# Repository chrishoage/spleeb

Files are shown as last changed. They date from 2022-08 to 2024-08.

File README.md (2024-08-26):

# Spleeb

Another split keyboard... a "Spleeb".

This split keyboard is created using [Ergogen](https://github.com/ergogen/ergogen/) and the routing done manually, copied back into the yaml file. This was inspired a lot by the Ergodash which I used for about a year but wanted something that fit my use and hands a bit better.

## ‼ NOTE ‼

Photos are pictured with heat set inserts in the bottom chassis that **_ARE NOT_** present in the STEP or Fusion 360 files. I was not happy with how the approach I took worked, and didn't want to release something that people may actually use (like the original touchpad bracket which was particularly poorly designed). I didn't want to reprint the bottom just to take some photos. The models in this repo are exactly the same, I just removed the holes for the heat set inserts on the side.

You can read more about the [Spleeb Chassis 1.2 revision in the Pull Request which added it](https://github.com/chrishoage/spleeb/pull/5).

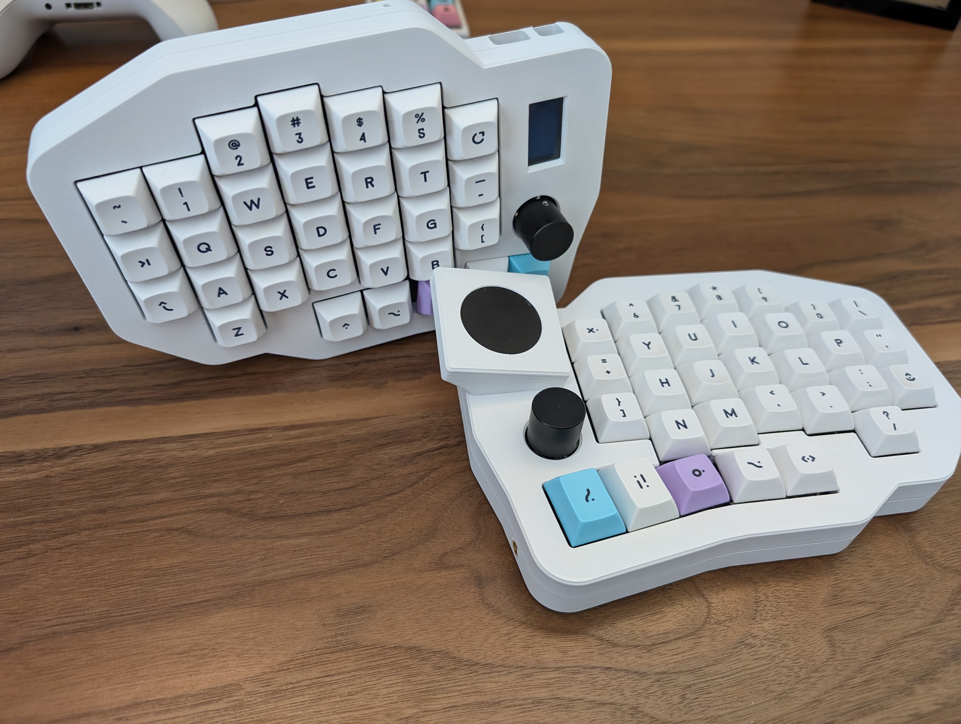
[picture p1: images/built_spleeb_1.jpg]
Spleeb Feature Photo

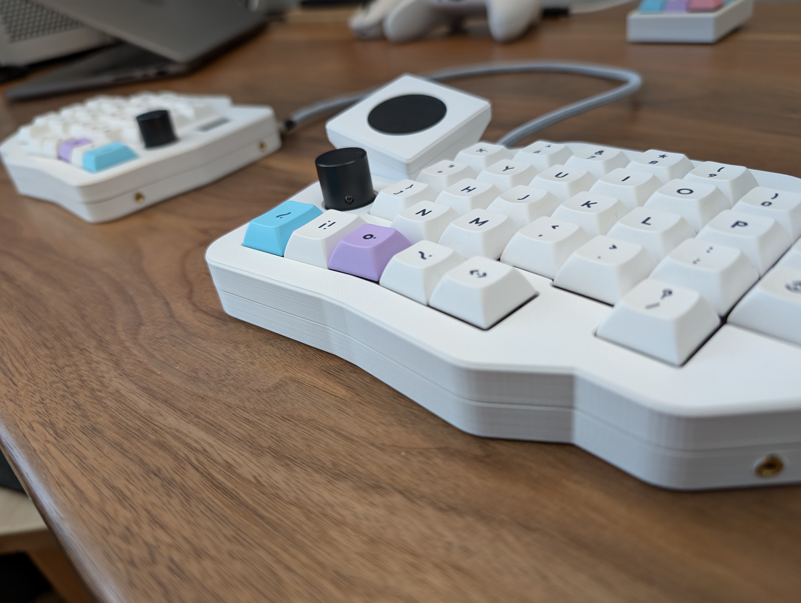
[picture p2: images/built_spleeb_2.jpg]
Spleeb Feature Photo

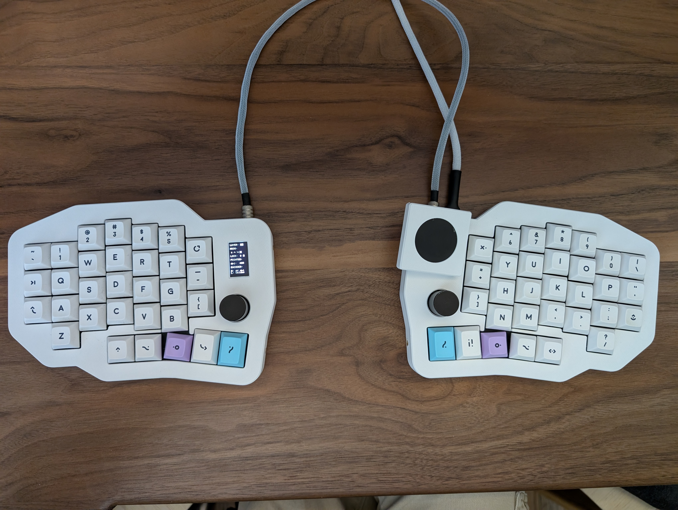
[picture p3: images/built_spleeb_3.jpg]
Spleeb Feature Photo

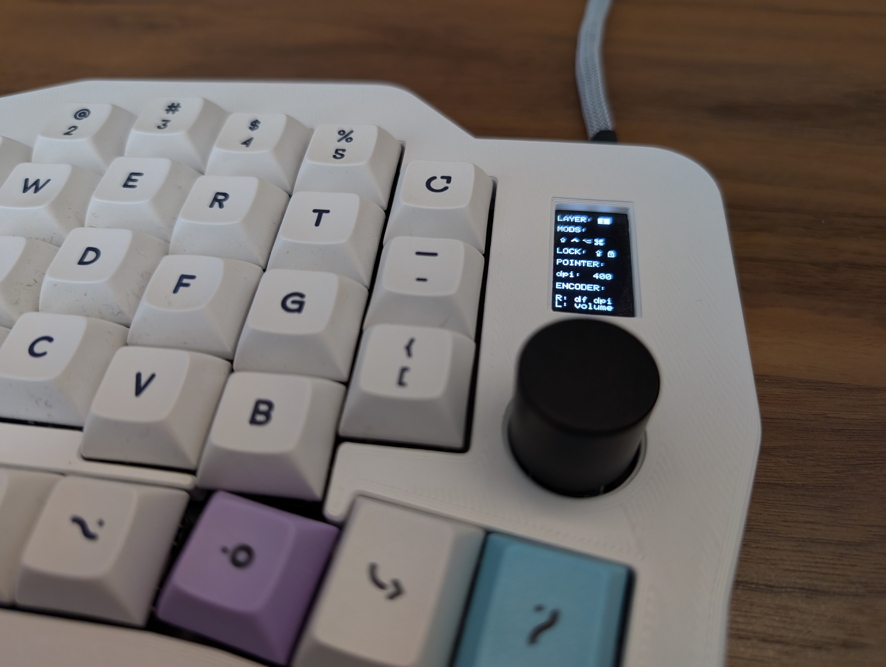
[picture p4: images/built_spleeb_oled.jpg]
Spleeb Feature Photo


### Features

- Reversible PCB
- Optional rotary encoder replacing the bottom left key switch
- OLED screen covering the MCU on the inside of the board
- No acrylic case, only 3D printed case and plate, or cut plate
- No RGB (a joke - I don't use LEDs on keyboards but am open to accepting PRs if someone wants to do the work)

| Left | Right |
| --- | --- |
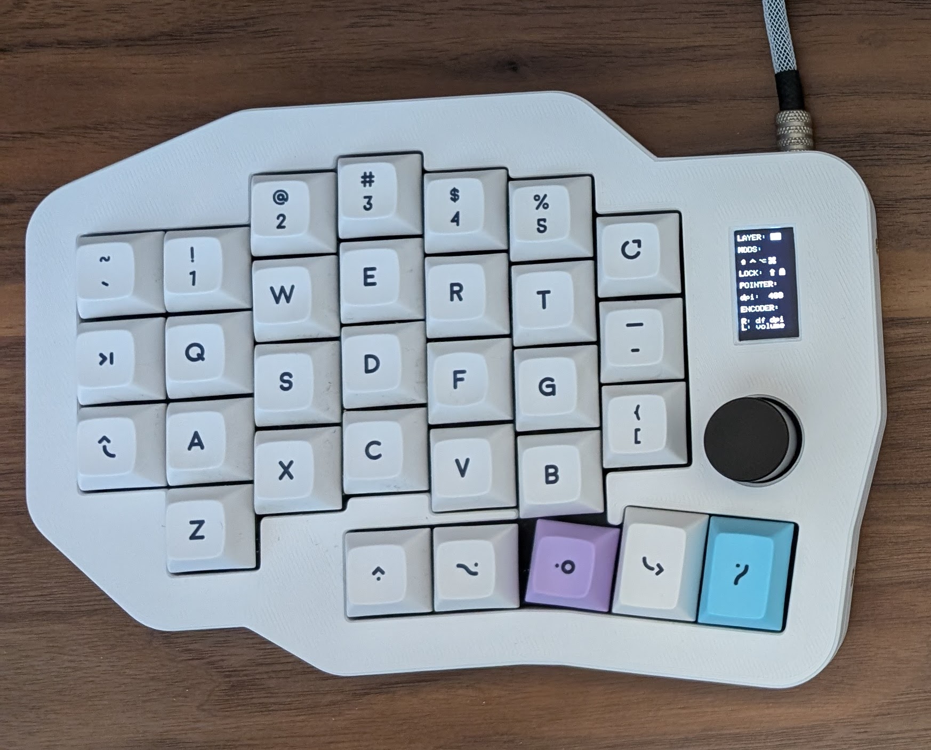
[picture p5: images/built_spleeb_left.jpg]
Left Spleeb
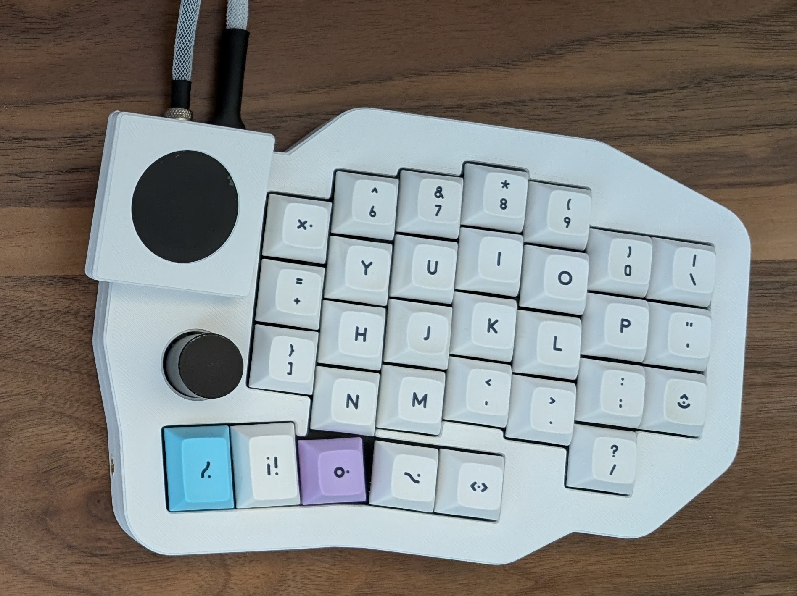
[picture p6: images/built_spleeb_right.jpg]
Right Spleeb
|  |  |
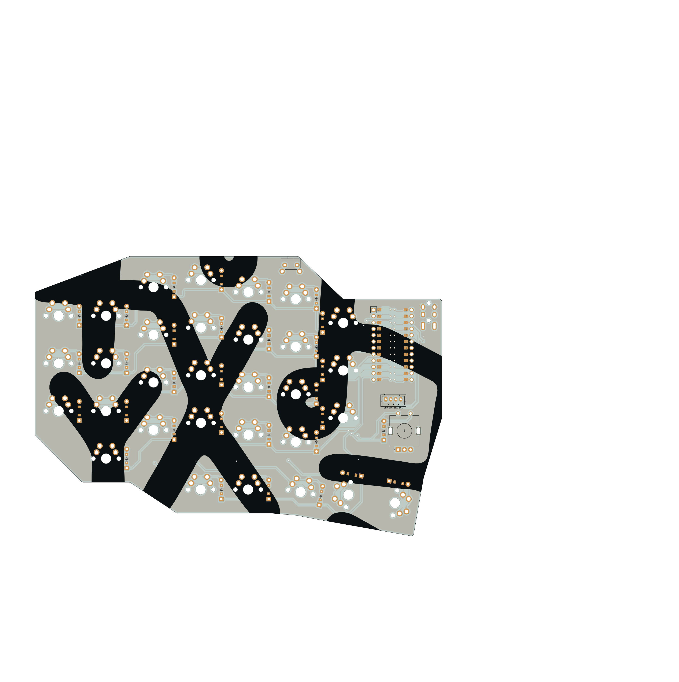
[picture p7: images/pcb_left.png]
Left Spleeb
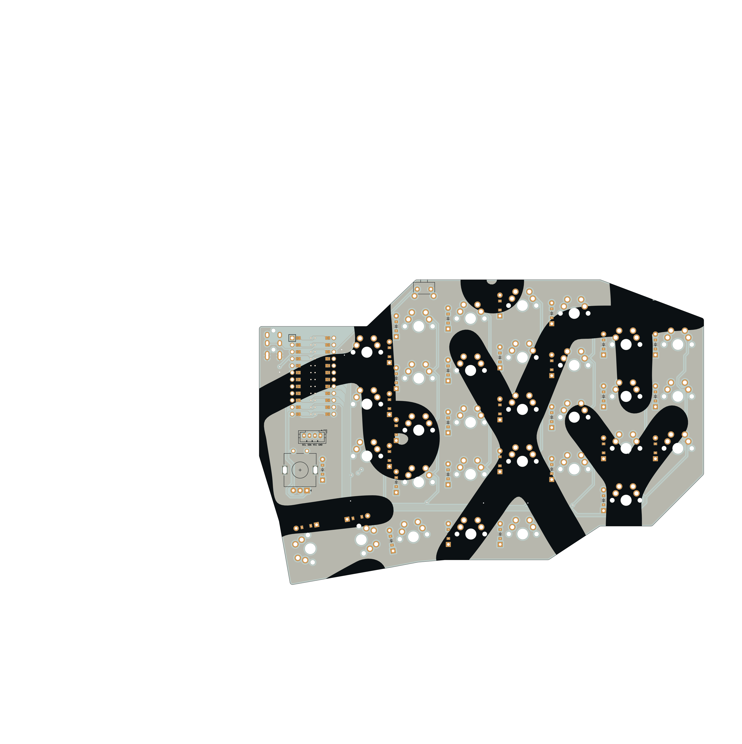
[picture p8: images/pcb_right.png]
Right Spleeb
|  |  |

### Motivation

I'm not a fan of excessive layers, and many of the popular split keyboards are 3x5 and make heavy use of layers. I used the Ergodash for a while but found the placement of the mods to be uncomfortable, and the top row of the thumb cluster to be unused. Seeing some keyboards (like the [bastard keyboards' dilemma](https://bastardkb.com/dilemma/)) which leveraged the Cirque touchpad inspired me to create my own keyboard which allowed for the layout I wanted, along with all the bells and whistles like rotary encoders, oled screen and touchpad. A secondary purpose of this was to learn Fusion 360, KiCad, and a teensy tiny bit of C and electrical engineering.

### BOM

| Item | Quantity | Notes |
| --- | --- | --- |
| Spleeb PCB | 2 | |
| Spleeb Plate | 2 | Intended to be cut from FR4 during PCB fab but this can be 3D printed. Extrude the plate dxf to 1.5mm and it will be 3d printable (fit accuracy depends on your printer) |
| Cirque 35mm Touchpad Flat overlay TM035035 | 1 | i2c only. The SPI version can be modified to use i2c. |
| SSD1306 128x64 OLED | 1 | DIYmall model and footprint used in chassis model. Other brands may have fit issues with out modification of the model. |
| Pro Micro pin MCU | 2 | RP2040 recomended. Boardsource Blok used in build |
| MX switches | 62 | |
| 1u keycaps | 58 | |
| 1.25u keycaps | 4 | |
| EC11 Encoder | 2 | Alps Alpine EC11N1524402 used in build |
| Encoder Kob | 2 | 18mm diameter |
| 1N4148 Through Hole Diodes | 64 | SMD diodes supported on PCB but this has not been tested |
| PJ-320A 3.5 mm jack | 2 | |
| Alps Alpine SKHLLCA010 | 2 | Reset Switch |
| JST PH 2.0 mm 4 pin straight connector | 2 | These are optional. Wires can be soldered directly to the though hole pads on the PCB. The connectors make disassembly easier. |
| Mill-Max 315-93 Low Profile Sockets | 48 | These are optional. However the height of regular headers is slightly higher than these, so may need adjusting to the USB cutout |
| Mill-Max 3320 Socket Pins | 48 | These are optional. These are for the Mill-Max sockets |
| Mill-Max 3305-1 Switch Sockets | 124 | These are optional. These allow switches to be swapped with out resoldering |
| M3 M3x5x4 threaded heat set inserts | 8 | Used to fasten bottom to top of chassis. (Same as the Voron 2.4/Trident BOM) |
| M3 12mm length socket head screws | 8 | Used to fasten bottom to top of chassis. 10mm _should_ work as well. |
| M2 4mm installed length threaded heat set inserts | 10 | Used to fasten plate to top and Cirque bracket to top. Up to 20 may be used depending on how much stiffness in the plate is desired. |
| M2 8mm length ultra low profile screws | 8 | Used to attach plate to top. Minimum 8. Up to 20 may be used depending on how many M2 heat set inserts are installed top top. |
| Silicone O-Rings, 4mm OD 1mm ID 1.5mm Width | 16 | Used for a poor man's burger mount isolation for the plate and top |
| M2 4mm length ultra low profile screws | 6 | 2-4 for the oled, 2 for the angled Ciruqe bracket |
| Hookup Wire | x | Needed for OLED and Cirque Touchpad |

### Build Notes (Spleeb Chassis rev 1.2)

Most of this build is straight forward and would follow any PCB build. Look for the diode silkscreen to know which direction didoes should go.

The original chassis CAD files created using Fusion 360 [are included](./chassis/) and the step files for all parts included as well.

There are [more photos](/images/) not shown in the readme in th images directory.

#### "Burger" Mount

Two silicone O-rings are to be placed in-between the plate and the contact points. One under the screw head and one under the plate. The plate is then screwed into the "top" of the chassis for a top mount approach.

The original plate had 10 attachment points for the "sandwich" mount chassis that was designed before this current iteration. In hindsight this was far too many. While the design and 3d models still support all 10 attachment points, only 4 need to be used.

I am currently using the two on each side of the plate and it feels just fine and there is no rattle. Tightening down the screws all the way is not necessary, just enough so that the plate doesn't move.

| | |
| --- | --- |
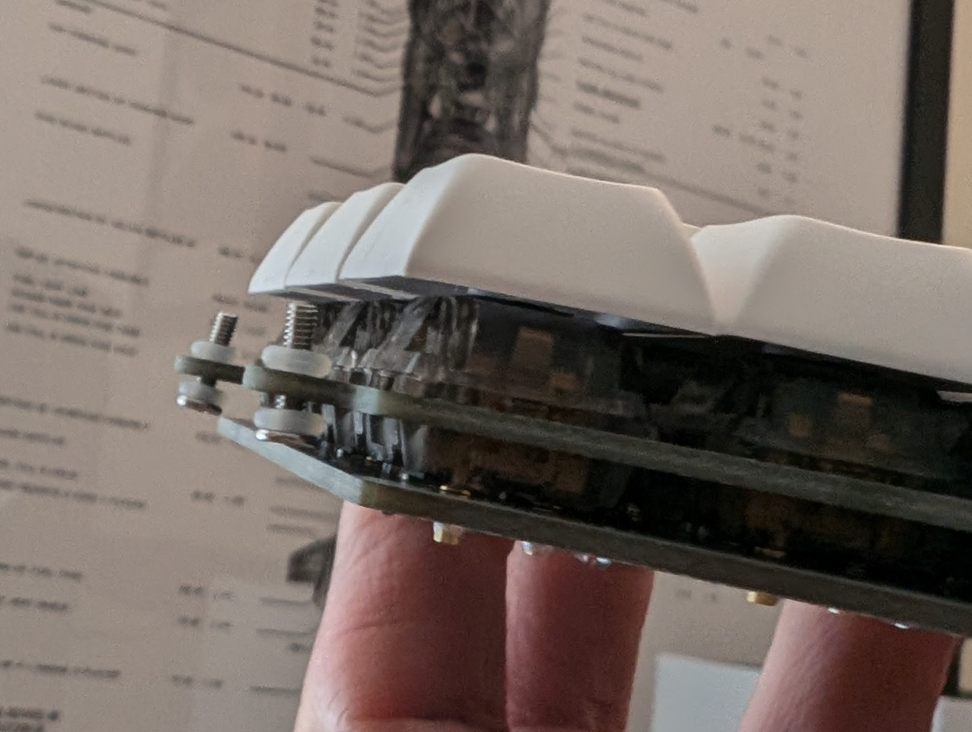
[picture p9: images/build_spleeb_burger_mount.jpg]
Burger mount example on plate
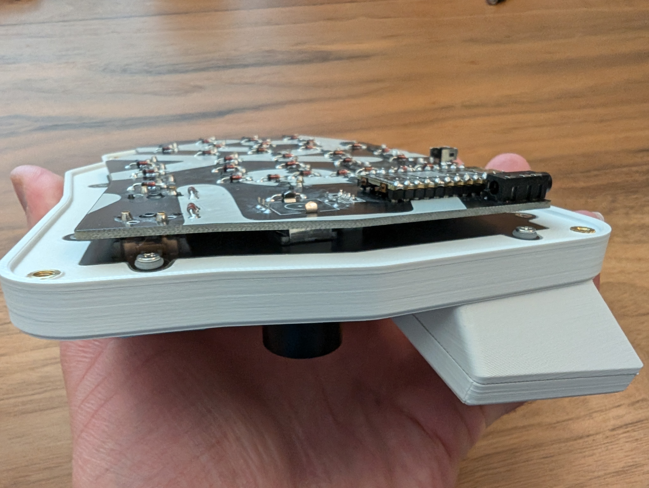
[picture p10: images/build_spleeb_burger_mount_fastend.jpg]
Burger mount fastened to the top chassis
|  |  |

#### MCU Mounting and MCU Solder pads

This PCB has solder pads on each side of the PCB. These solder pads allow the MCU to be mounted on either side of the PCB - however the intended use for this build is mounting the MCUs on the _underside_ of the PCB - the side opposite the switches, with the MCU LED facing up. With this orientation the solder pads should be solder on the \*same side as the switches.

The solder pad opposite the through hole pad marked with the square 🔳 is RAW.

If you mount the MCU with the LED facing out on the top (same side as switches) you would solder the pads on the top.

If you mount the MCU with the LED facing out on the bottom (opposite side of switches) you would solder the pads on the bottom.

If you mount the MCU with the LED facing in on the top (same side as switches) you would solder the pads on the bottom.

If you mount the MCU with the LED facing in on the bottom (opposite side of switches) you would solder the pads on the top.

Again - with the chassis as designed the last mounting option is the only one supported:

Mount the MCU on the opposite side of the switches, with the LED facing in. Solder the pads on the same side as the switches.

| MCU Orientation | Solder pads on top |
| --- | --- |
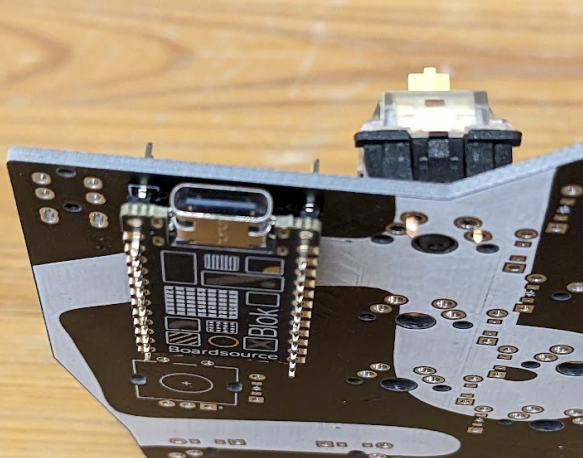
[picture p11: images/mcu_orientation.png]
MCU mounted to the PCB ready to be soldered
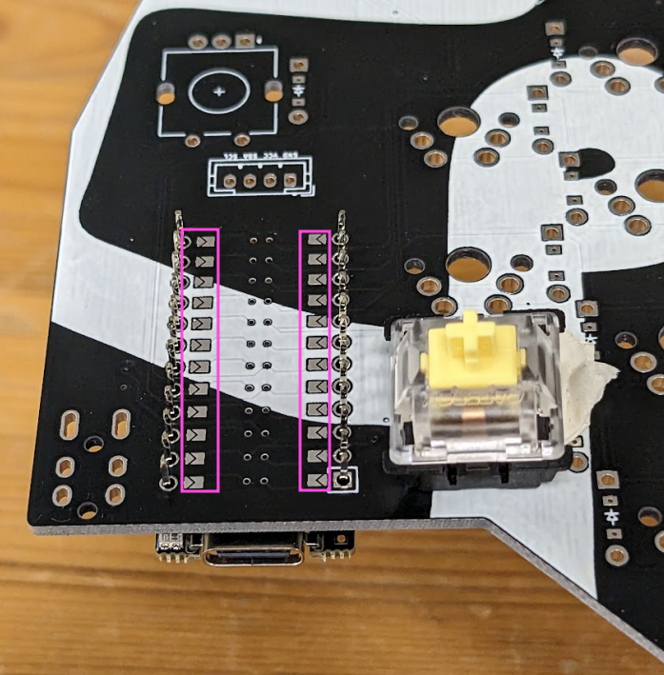
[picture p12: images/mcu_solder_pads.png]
Where to solder the pads (on the opposite side of the MCU)
|  |  |

Since the PCB is reversible you would mirror this on the other side.

#### Cirque 35mm Touchpad

Use hookup wire to solder to the GND, VCC, SDA, SCL pads, and remove the R1 resistor if the SPI version was purchased.

#### JST PH 2.0 connector

Wires should be hooked up to connector from the "outside" edge of the pcb to "inside" (PCB is reversible)

1. SCL ("outside" - white)
1. SDA (yellow)
1. VCC (red)
1. GND ("inside" - black)

#### Cirque Touchpad Bracket

The bracket is split into three parts.

- _Support_: 35mm Cirque touchpad sits in the support. The support has indexing features to hold the touchpad in the correct orientation. The "L" embossed in the support is a rudimentary X/Y plane to remember orientation.
- _Bezel_: The Support snaps into place inside the bezel.
- _Bracket_: The Support + Bezel assembly snaps on top of the bracket which holds the assembly at a 15° angle.

| | |
| --- | --- |
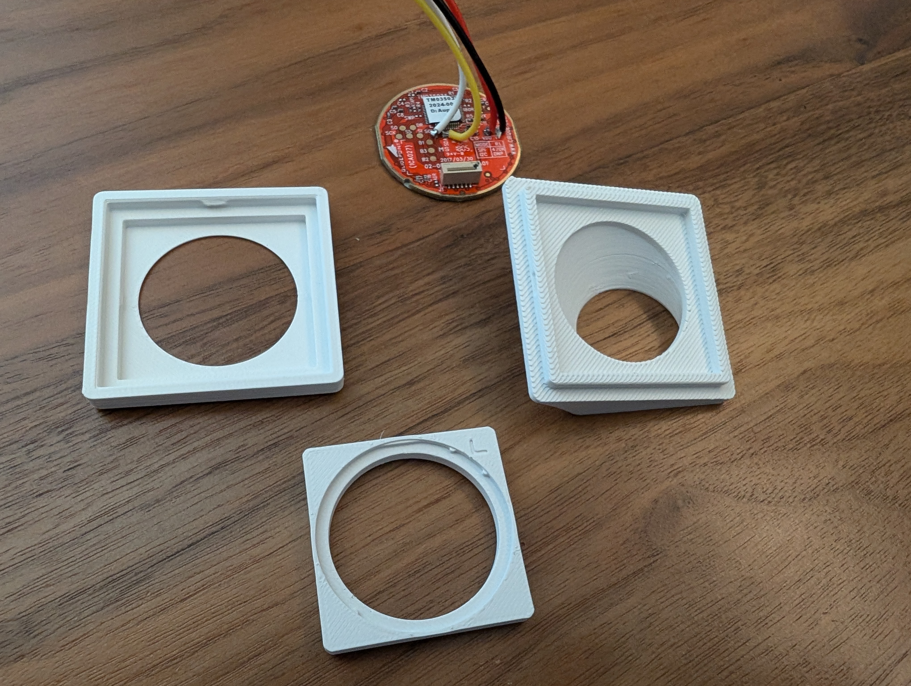
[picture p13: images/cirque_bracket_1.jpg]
All of the parts needed to assemble the bracket
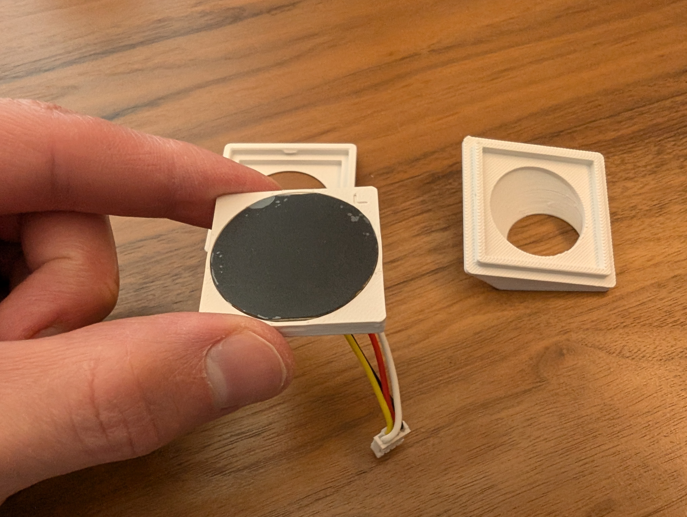
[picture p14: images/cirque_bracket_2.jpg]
Place the trackpad in the support
|  |  |
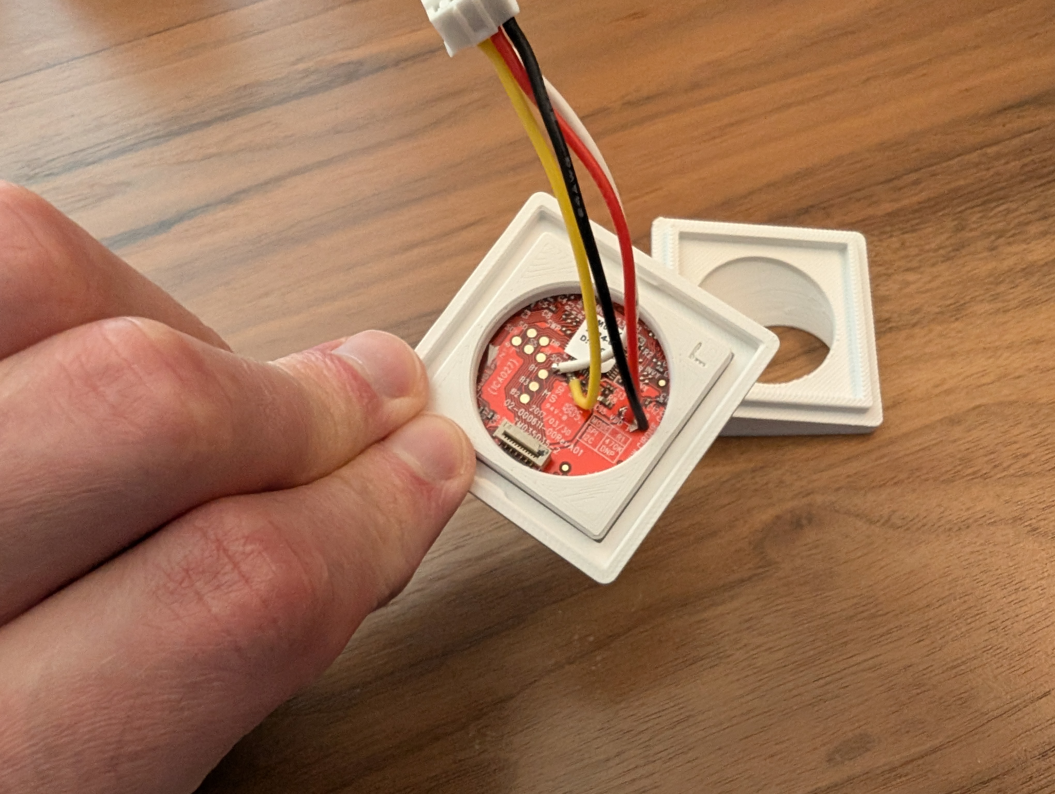
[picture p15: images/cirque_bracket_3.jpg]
Place the support in the bezel, it snaps in
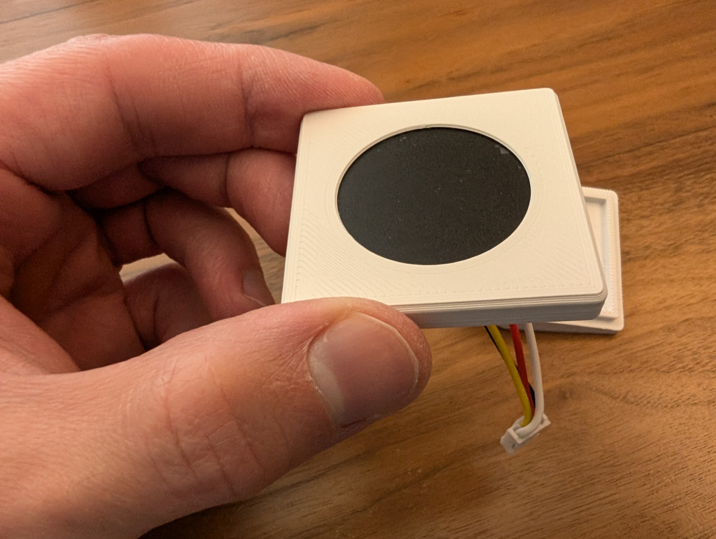
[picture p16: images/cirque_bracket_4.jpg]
What the support looks like snapped in the bezel
|  |  |
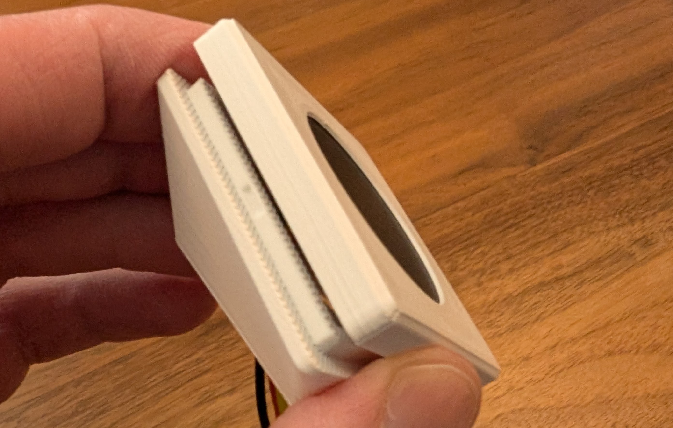
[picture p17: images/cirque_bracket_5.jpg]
Support + Bezel assembly snaps on top of the bracket
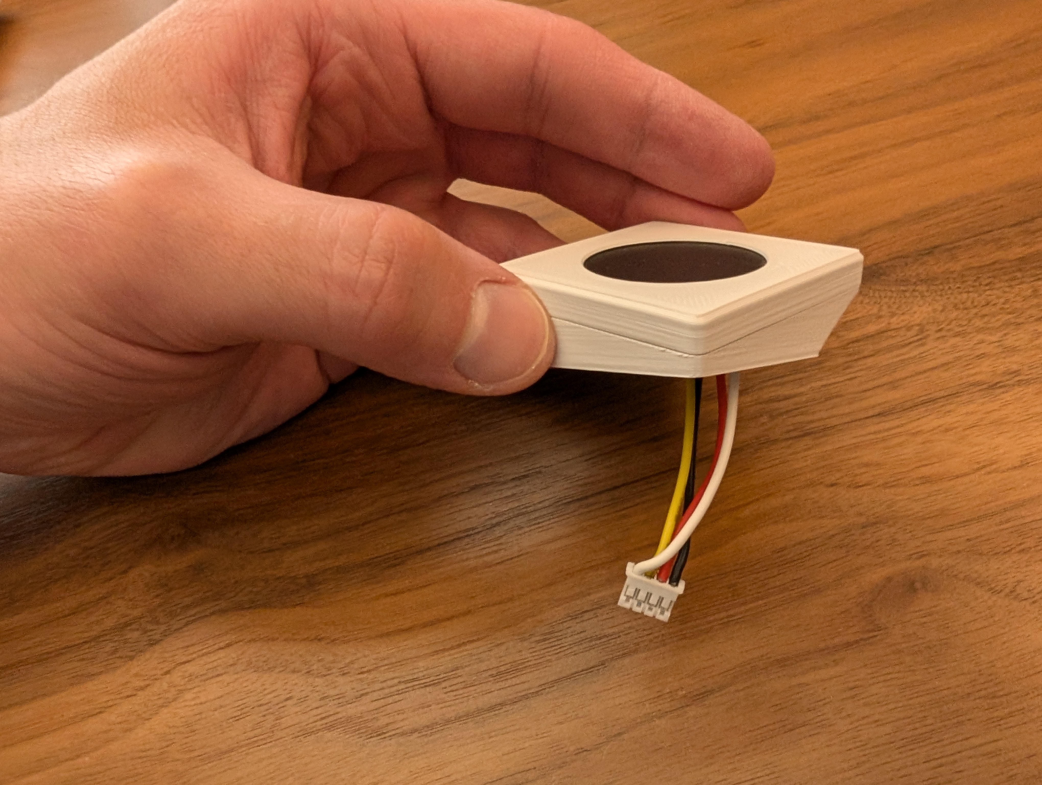
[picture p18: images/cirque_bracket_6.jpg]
Fully assembled touchpad bracket
|  |  |

#### OLED attachment

The intent is that the 4mm ultra low profile screws should fasten directly into the plastic.

### Printing

I used ASA but anything should work depending on your printer. I didn't use supports for the 3.5mm and USB cutouts. YMMV on needing supports, but I designed the model to be printed with out supports.

#### Critical print parameters

There are features in this model which demand a 0.4 nozzle and 0.2mm layer hight. All other printing parameters are to taste.

### Firmware

Firmware is QMK based and [can be found in the QMK GitHub repo](https://github.com/qmk/qmk_firmware/tree/master/keyboards/spleeb).

My personal keymap customizations [can be found my my QMK Userspace Fork](https://github.com/chrishoage/qmk_userspace/tree/main/keyboards/spleeb/keymaps/chrishoage)

## License

- All code in this repository is licensed under the [MIT](./LICENSE) license.
- All images in this repository are licensed under the [Creative Commons Attribution-NonCommercial](https://creativecommons.org/licenses/by-nc/4.0/) license.
- All CAD files in this repository are licensed under the [Creative Commons Attribution-NonCommercial-ShareAlike](https://creativecommons.org/licenses/by-nc-sa/4.0/) license.

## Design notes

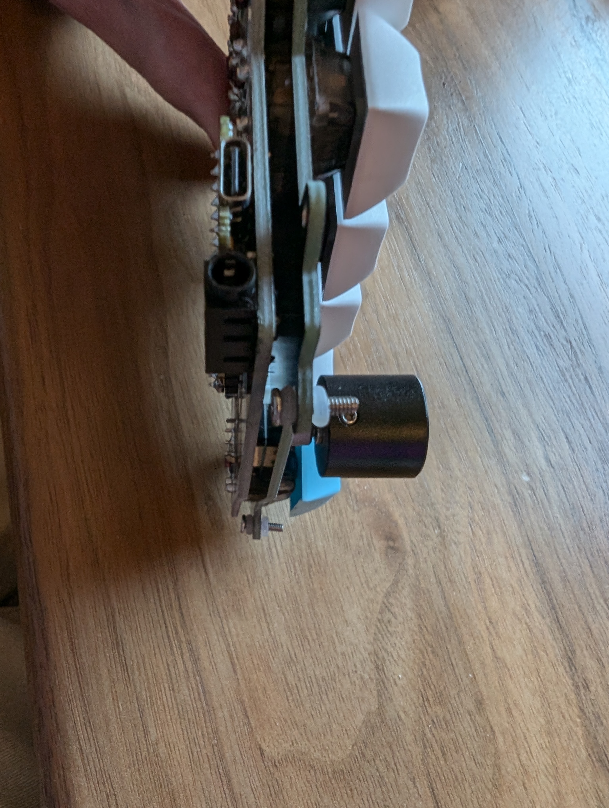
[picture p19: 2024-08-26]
images/built_spleeb_pcb_with_plate_side_profile.jpg

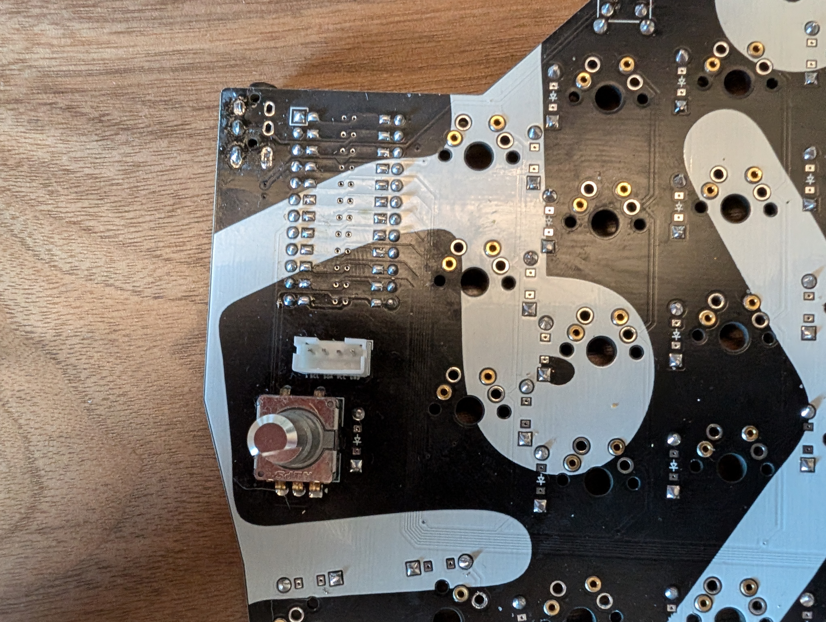
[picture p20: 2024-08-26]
images/built_spleeb_pcb_3.jpg

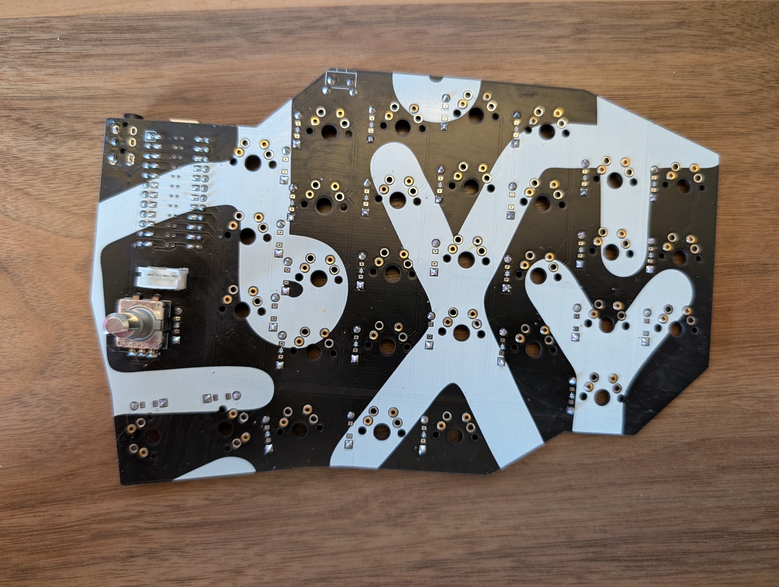
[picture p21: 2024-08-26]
images/built_spleeb_pcb_2.jpg

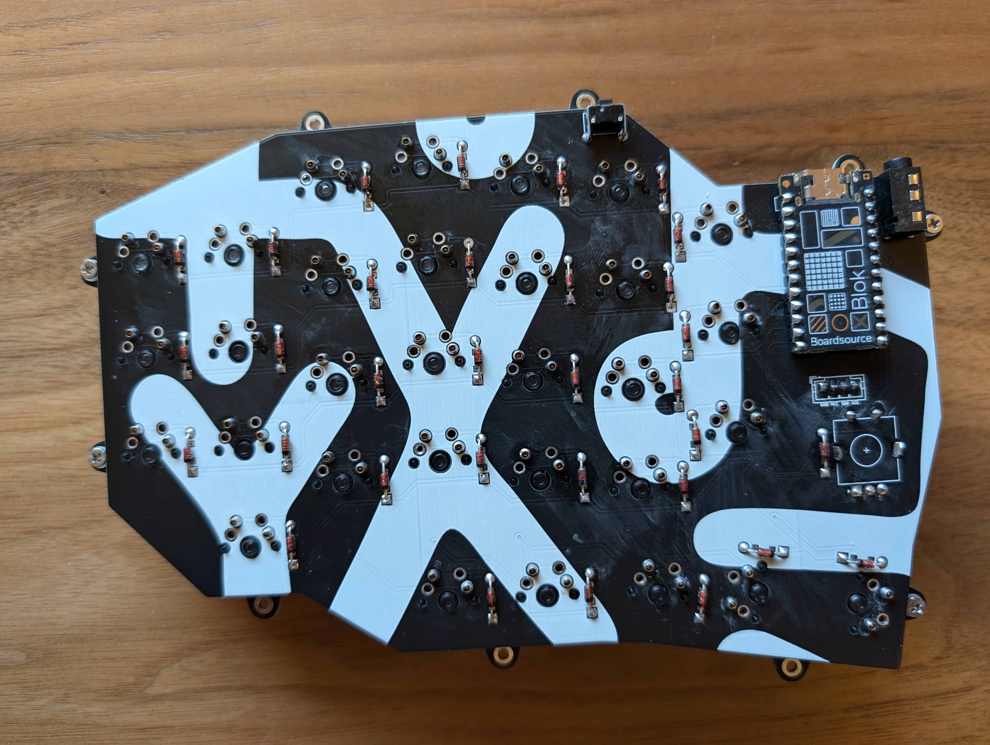
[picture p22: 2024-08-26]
images/built_spleeb_pcb_1.jpg

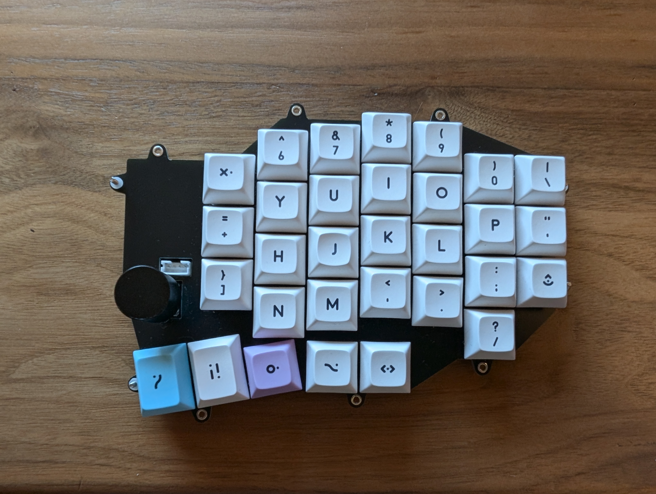
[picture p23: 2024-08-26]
images/built_spleeb_pcb_with_plate.jpg

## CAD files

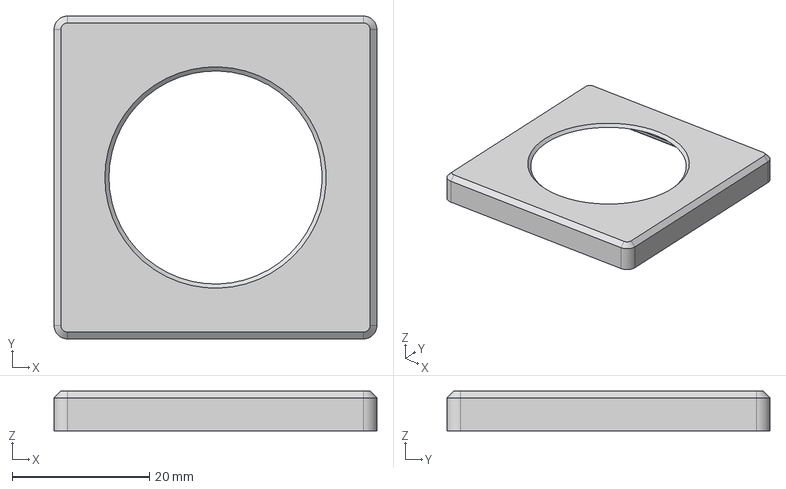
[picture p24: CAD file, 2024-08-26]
chassis/Angled Cirque Bracket Bezel.step
47.0 x 47.0 x 5.80 mm

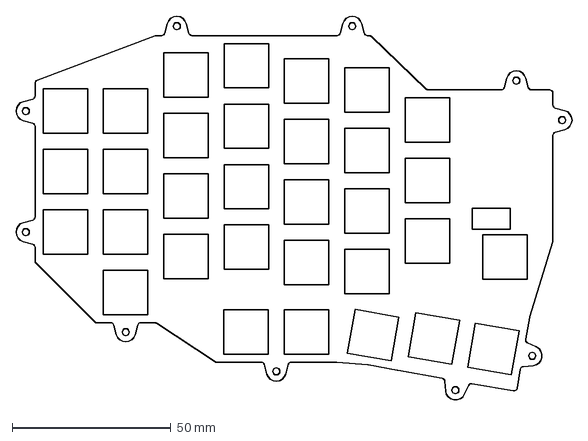
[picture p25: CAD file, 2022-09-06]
spleeb/outlines/plate.dxf
175.1 x 121.0 mm

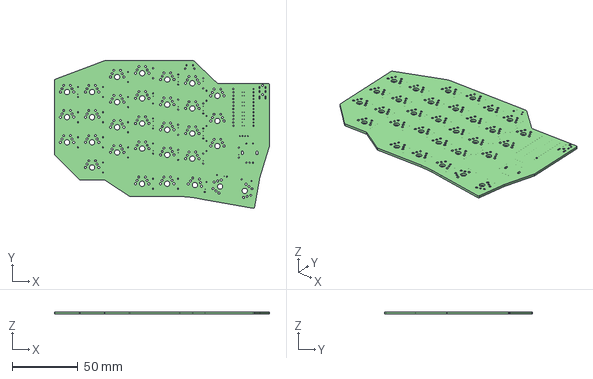
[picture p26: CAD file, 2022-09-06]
spleeb/pcbs/spleeb.step
163.1 x 111.9 x 1.60 mm

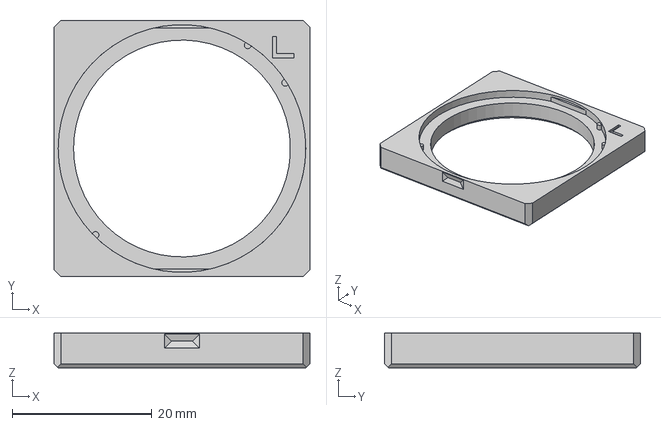
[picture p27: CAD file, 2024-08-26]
chassis/Angled Cirque Bracket Support.step
36.6 x 36.6 x 5.00 mm

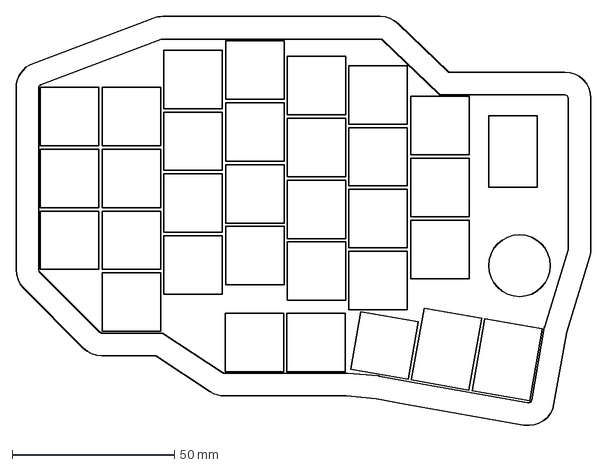
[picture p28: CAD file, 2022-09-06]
spleeb/outlines/preview.dxf
177.1 x 126.6 mm

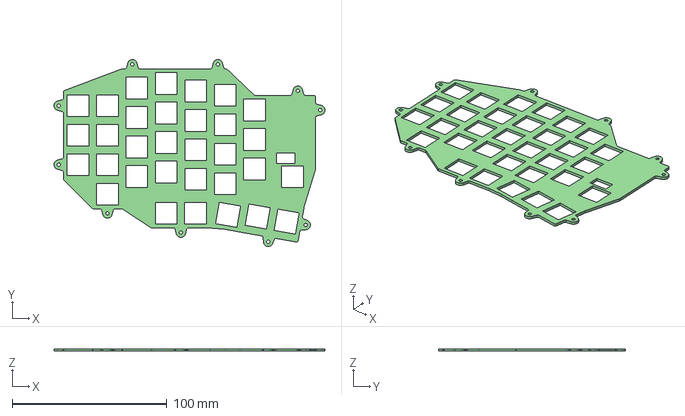
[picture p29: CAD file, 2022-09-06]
spleeb/pcbs/plate.step
175.1 x 120.8 x 1.60 mm

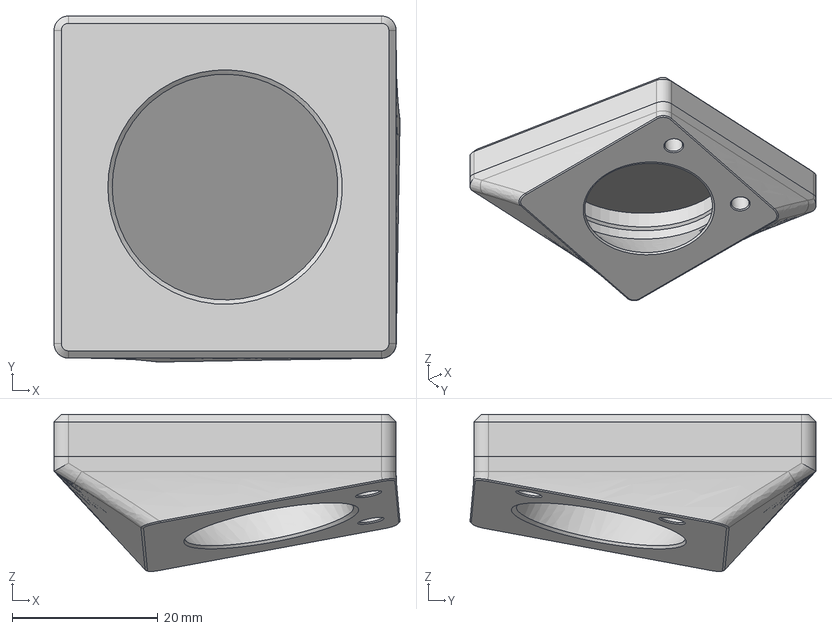
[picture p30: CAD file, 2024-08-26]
chassis/Angled Cirque Bracket.step
47.5 x 47.5 x 21.6 mm
Trackpad
Bezel
Support
Bracket

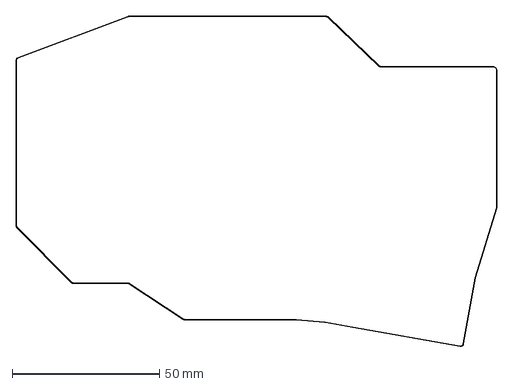
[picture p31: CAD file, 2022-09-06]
spleeb/outlines/pcb_outline.dxf
163.1 x 112.0 mm

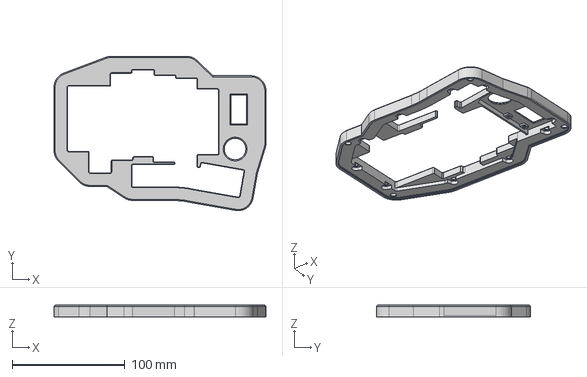
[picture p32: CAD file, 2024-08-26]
chassis/Spleeb Left Top.step
187.9 x 136.7 x 10.2 mm

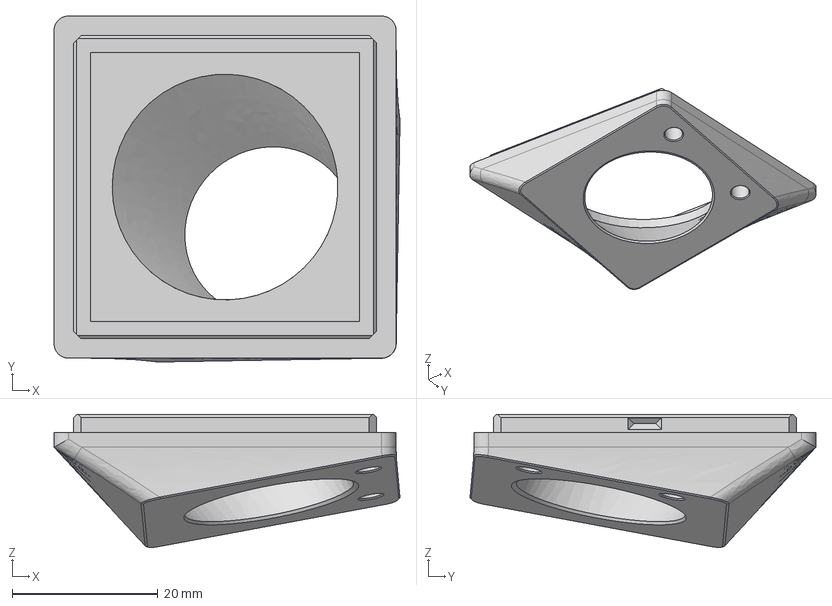
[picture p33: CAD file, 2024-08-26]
chassis/Angled Cirque Bracket Bracket.step
47.5 x 47.5 x 18.3 mm

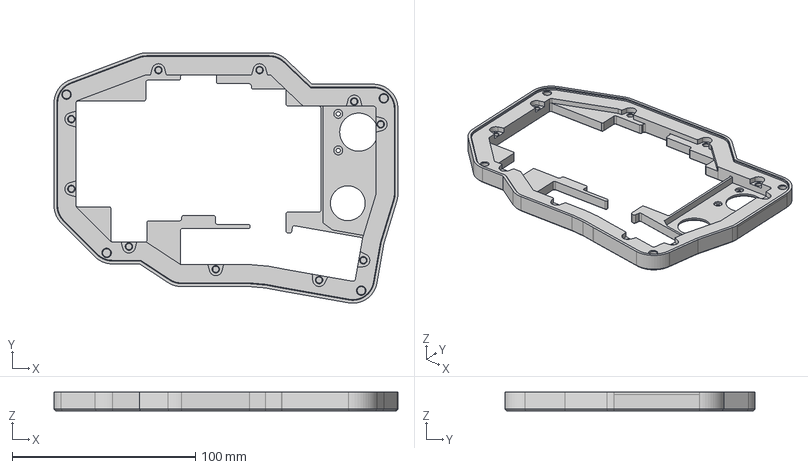
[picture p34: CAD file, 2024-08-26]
chassis/Spleeb Right Top.step
187.9 x 136.7 x 10.2 mm

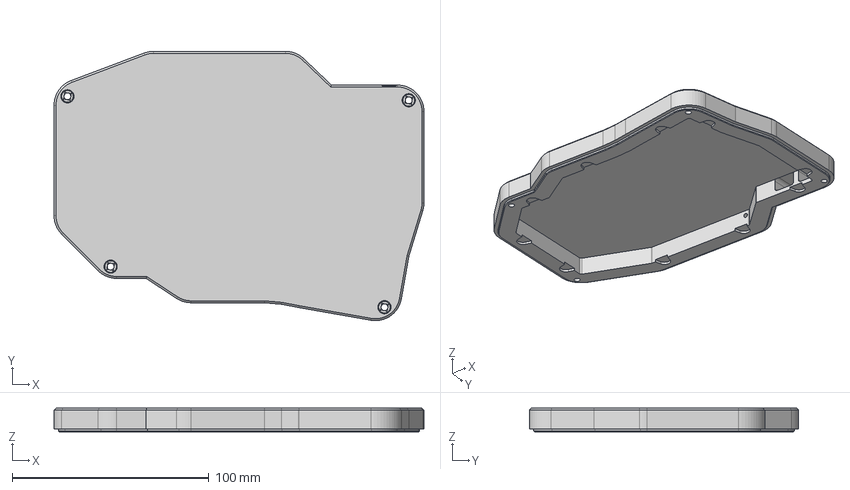
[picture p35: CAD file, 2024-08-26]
chassis/Spleeb Right Bottom.step
187.9 x 136.7 x 12.1 mm

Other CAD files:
chassis/Spleeb Left Bottom.step
chassis/Angled Cirque Bracket.f3d

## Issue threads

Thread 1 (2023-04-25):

I have a question about build

MinHyeong-Lee, 2023-04-25:
Hi friend, I build spleeb keyboard that you designed these days. I have a few questions. I'm a beginner. :(

**Image for Q1, Q2 https://postimg.cc/DWTQpYrH**

**Q1 (Green Color)**. What is this? Should I solder here any components???

**Q2 (Red Color)** . Is the diode direction of the part I marked in red the right direction?

-----
**Image for Q3 https://postimg.cc/bsBdv63M**

**Q3**. Should I build in the order of the pictures? Is this right? layer 0 (MX switch) layer 1 (spleeb plate) layer 2 (spleeb pcb, with soldered diode, rotary encoder) layer 3 (PJ-320A 3.5 mm jack, MCU)

I drew with my hands because I am not good at English. I hope you can understand.

Your keyboard is so cool. I'll make sure to build it and send you a picture

Thank you.

chrishoage, 2023-04-25:
> Q1 (Green Color). What is this? Should I solder here any components???

Thank you for pointing this out! I had accidentally kept this out of the BOM

I have updated it here https://github.com/chrishoage/spleeb/commit/5231b6fe8878e6d334b1f7b3b07c349e56742b73

> Q2 (Red Color) . Is the diode direction of the part I marked in red the right direction?

Yes the diode direction correct. The silkscreen makes it hard to tell, but another way is to use the square pad as an indicator. The square pad is the direction of the cathode part of the diode.

> Q3. Should I build in the order of the pictures? Is this right? layer 0 (MX switch) layer 1 (spleeb plate) layer 2 (spleeb pcb, with soldered diode, rotary encoder) layer 3 (PJ-320A 3.5 mm jack, MCU)

Yes that is all correct. The "side" you solder the diodes to don't matter. I soldered my diodes underneath the PCB but it was just personal preference.

The most important part is the MCU orientation which it seems you got correct from your drawing.

You would solder the pads on the opposite side of the MCU

Closed 2023-05-18.

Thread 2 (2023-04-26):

compile firmware issue

MinHyeong-Lee, 2023-04-26:
Thank you for your answer last time, it was very helpful. 👍

I have a new problem 😢
An error occurred while compiling firmware.

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

default keymap compile works well
but your keymap not work on my env :(

Q1. How can I compile keymap chrishoage?

Q2. I used for build spleeb with MCU KB2040
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

The pinout of each mcu seems to be slightly different. Should I fix some code when compiling firmware?

Thank you.

chrishoage, 2023-04-26:
I can reproduce the compile errors. It looks like things changed since I wrote the original firmware and broke my keymap.

I will spend some time this week/weekend to open a PR for QMK to fix the keyamp

> Q2. I used for build spleeb with MCU KB2040
> The pinout of each mcu seems to be slightly different. Should I fix some code when compiling firmware?

Yes you will need to update the pins in the firmware to mach any pin changes. It looks like the KB2040 only has a few pins different, so it should be a simple update.

You can use the `default` firmware to ensure the pins are correct.

chrishoage, 2023-04-26:
```diff
diff --git a/keyboards/spleeb/keymaps/chrishoage/keymap.c b/keyboards/spleeb/keymaps/chrishoage/keymap.c
index 2650c1aebf..c3dfb8f02b 100644
--- a/keyboards/spleeb/keymaps/chrishoage/keymap.c
+++ b/keyboards/spleeb/keymaps/chrishoage/keymap.c
@@ -4,7 +4,7 @@
 #include QMK_KEYBOARD_H

 // Double tap TD(0) to enter bootloader
-static void enter_qk_boot(qk_tap_dance_state_t *state, void *user_data) {
+static void enter_qk_boot(tap_dance_state_t *state, void *user_data) {
     if (state->count >= 2) {
         reset_keyboard();
         reset_tap_dance(state);
@@ -13,7 +13,7 @@ static void enter_qk_boot(qk_tap_dance_state_t *state, void *user_data) {

 enum SpleebLayer { _BASE = 0, _FN, _MOUSE };

-qk_tap_dance_action_t tap_dance_actions[] = {[0] = ACTION_TAP_DANCE_FN(enter_qk_boot)};
+tap_dance_action_t tap_dance_actions[] = {[0] = ACTION_TAP_DANCE_FN(enter_qk_boot)};

 // clang-format off
 const uint16_t PROGMEM keymaps[][MATRIX_ROWS][MATRIX_COLS] = {
```

I have not loaded it onto my keyboard yet to test but this diff makes my keymap compile.

chrishoage, 2023-04-30:
@MinHyeong-Lee I have opened a PR to fix it in QMK https://github.com/qmk/qmk_firmware/pull/20644

The branch in the PR will allow you to build (I have verified with my own keyboard)

MinHyeong-Lee, 2023-05-01:
> @MinHyeong-Lee I have opened a PR to fix it in QMK [qmk/qmk_firmware#20644](https://github.com/qmk/qmk_firmware/pull/20644)
>
> The branch in the PR will allow you to build (I have verified with my own keyboard)

I checked that your PR was merged. Compile firmware also works well. Thank you!!

By the way, can I ask you one more time about the direction of soldering?
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

I soldered my KB2040 under the spleeb PCB, and soldered solder pads same direction with switches
Is this right??

Thank you :)

chrishoage, 2023-05-01:
> soldered solder pads same direction with switches. Is this right??

Unfortunately no, forgive my poor explanation in the readme.

You need to solder the pads on the side the switches are facing, not the side the switches are soldered.

The pads should be soldered on the opposite side of the MCU when the MCU is in the orientation you have it.

You will need to de-solder the MCU, wick up the solder on the pads (ensure there is no bridge) then resolder the MCU.

The MCU is correct in your picture, however the pads should not be soldered on the same side.

chrishoage, 2023-05-03:
@MinHyeong-Lee In my most recent commit (https://github.com/chrishoage/spleeb/commit/7b96cb6b1492c2ee43bb1804438142b8a255d928) I have added photos to help better demonstrate the correct place to solder the pads.

Apologies for the confusion

MinHyeong-Lee, 2023-05-18:
> @MinHyeong-Lee In my most recent commit ([7b96cb6](https://github.com/chrishoage/spleeb/commit/7b96cb6b1492c2ee43bb1804438142b8a255d928)) I have added photos to help better demonstrate the correct place to solder the pads.
>
> Apologies for the confusion

Thank you. It helped me a lot!! :)

Closed 2023-05-18.

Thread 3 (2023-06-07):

Cirque trackpad question

MinHyeong-Lee, 2023-06-07:
Thanks to your help, switch works well, and the OLED works well! :)
The last step is the cirque trackpad.

If I use chrishoage keymap, do I just touch it to use the cirque trackpad?
I removed the R1 resistor for I2C operation.

**mcuconf.h**
```C
#pragma once

#include_next <mcuconf.h>

#undef RP_I2C_USE_I2C1
#define RP_I2C_USE_I2C1 TRUE
```

**halconf.h**
```C
#pragma once

#define HAL_USE_I2C TRUE

#include_next <halconf.h>
```

I checked datasheet for kb2040 that SDA and SCL are GP2, GP3 and I2C1
I don't think I did anything wrong in particular. Can you give me some advice to refer to for the cirque trackpad?

I really appreciate your help in resolving the problem.😁

chrishoage, 2023-06-09:
> I checked datasheet for kb2040 that SDA and SCL are GP2, GP3 and I2C1

Since the oled is working for you I don't think you have any issue with configuration.

>  I don't think I did anything wrong in particular. Can you give me some advice to refer to for the cirque trackpad?

It's difficult to say with out being able to debug myself, however you can compile the firmware in debug mode - you should see logs if it detects the touchpad over i2c.

I would double check the wiring to ensure all the wires are going to the right spots on the PCB and the touchpad.

Beyond that it's difficult to say what may be the issue.

If you have further questions while trying to debug this please reach out!

MinHyeong-Lee, 2023-06-09:
>

There is a possibility that the cirque trackpad I purchased is defective, so I will buy more spare parts and test it. Thank you!

chrishoage, 2023-06-09:
Some more ideas if you struggle with this

1. I bought one of these while doing the firmware https://www.aliexpress.us/item/2255800970134605.html along with a 12 pin cable to match so I could test the board touchpad with out soldering wires
2. If you have a spare kb2040 and a breadboard you can try making a simple qmk firmware that tries to get the touchpad to work
3. compile and load the i2c scanner and see if it can find both the oled and the touchpad https://github.com/qmk/qmk_firmware/tree/master/keyboards/handwired/onekey/keymaps/i2c_scanner
4. If you do buy an extra touchpad try getting it working with SPI, a breadboard and a spare kb2040. Once you know it's working you can take off the resistor, rewire for i2c and again reconfigure and test

Again since the OLED is functioning for you it's unlikely to be a configuration issue (assuming the touchpad is on the right half - since my firmware uses the right half as the master)

MinHyeong-Lee, 2023-06-09:
Thank you! When the new touchpad arrives, I will test it with the method you told me

Anyway, can I ask about spleeb firmware?
Inspired by your firmware, I applied an independent encoder layer to other keyboard.

I have an RGB indicator on my keyboard, so I want to express colors according to the current encoder layer.

But I don't know how to use `spleeb_get_encoder_mode()` in keymap.c because I'm not good at C language.

For example, in my keymap.c
```C
bool process_record_user(uint16_t keycode, keyrecord_t *record) {
   switch (keycode) {
      case ENC_STR:
            if(spleeb_get_encoder_mode() === 0) rgblight_sethsv_at(HSV_RED, 2); // led 2
             blah blah // I want to get encoder layer at here and set rgb light
   }
}
```

When I use spleeb_get_encoder_mode() function at mykeyboard.c
RGB Indicator not works (The light comes on and goes out right out)
```C
bool process_record_kb(uint16_t keycode, keyrecord_t* record) {
#ifdef SPLEEB_ENCODER_MODE_MAP_ENABLE
    switch (keycode) {
        case ENC_MODE_STEP_RIGHT:
            if (record->event.pressed) {
                spleeb_step_encoder_mode(&g_spleeb_config, 1);
                switch (spleeb_get_encoder_mode(&g_spleeb_config, 1)) {
                    case 0:
                        rgblight_sethsv_at(HSV_RED, 2); // led 2
                        break;
                    case 1:
                        rgblight_sethsv_at(HSV_GREEN, 2); // led 2
                        break;
                    case 2:
                        rgblight_sethsv_at(HSV_WHITE, 2); // led 2
                        break;
                    case 3:
                        rgblight_sethsv_at(HSV_YELLOW, 2); // led 2
                        break;
                }
            }
            break;
    }
#endif // SPLEEB_ENCODER_MODE_MAP_ENABLE

    return true;
}
```
Thank you always from the bottom of my heart.😊

chrishoage, 2023-06-09:
> The light comes on and goes out right out

I unfortunately I have not worked with QMK an leds so I won't be super helpful here.

Since the light is turning on it seems like you're on the right track.   Maybe something is turning off the LED somewhere?

I will note that you can probably use the userland `process_record_user` for this in your keymap with out overriding any of the `process_record_kb` code.

You can check if the keycode is `ENC_MODE_STEP_RIGHT` and change your lights there. You should be able to get the current encoder mode using the functions defined in spleeb.c from there

MinHyeong-Lee, 2023-06-11:
>

I used `qmk console` command for debugging.
Changes occur in the terminal for all keys except trackpad.

What's interesting is that if I touch the trackpad while plug in/out usb to spleeb, sometimes it automatically moves to layer3, which is the mouse layer. It makes me think trackpad is connected well??... Hmm.. 😓
But once layer move to layer 3, it doesn't come back to layer 1.

So I have to plug in/out usb for reboot my keyboard again.

I haven't tried a lot of debugging yet. I haven't checked how to use functions like dprintf() in the "spleeb.c", "keymap.c" file yet.

Thank you

chrishoage, 2023-06-11:
Are you certian the trackpad is wired to the pcb correctly? The wiring will be mirrored.

If the oled and the trackpad have the same wire order on both halves of the pcb that would be the issue - they should be mirrored

MinHyeong-Lee, 2023-06-12:
> Are you certain the trackpad is wired to the pcb correctly? The wiring will be mirrored.
>
> If the oled and the trackpad have the same wire order on both halves of the pcb that would be the issue - they should be mirrored

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

Is this right??

chrishoage, 2023-06-12:
The colors threw me off for a sec but yes that does appear to be correct

I notice that you have quite long exposed wires connected to the pads. How are you testing the touchpad? Is it in the chassis?

In any case it would be a good idea to make sure you don't have any shorts on those wires when using them.

They look like they have enough bare wire exposed that they could very easily touch.

MinHyeong-Lee, 2023-06-12:
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

 Cirque trackpad is being tested without a case.
Just test the trackpad like in the picture.

If the solder direction is not a problem,  I should check the wires and other problems again.

Thanks..

MinHyeong-Lee, 2023-06-22:
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

II bought a new trackpad and this time I cut the wire short..

As soon as I connect to the keyboard, the mouse moves for a few seconds and the trackpad doesn't work again
😂 My KB2040 is offer 3.3V and I think I'm having issues elsewhere.
I don't think there's any more hope. I already bought 4 trackpads.

MinHyeong-Lee, 2023-06-22:
Thank you Chris Hoage :)
I just tested with another KB2040.
Cirque trackpad on my friend's spleeb works well.
But after I unplug JST cable and plug in again, it didn't work again.
I think the cirque trackpad is normal. Wire seems to be the problem. Sometimes it works, sometimes it doesn't.

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

I want to show you my left side of spleeb haha
I'll show you my right side after solving problem..

Thanks again.
Have a nice day!

chrishoage, 2023-06-22:
The left side looks great!!

>  I just tested with another KB2040.
> Cirque trackpad on my friend's spleeb works well.
> But after I unplug JST cable and plug in again, it didn't work again.

Something I didn't think to ask before, but your comment here made me curious.

Have you tested continuity of the JST-PH connection with a multi-meter?

I'm wondering if there is a crimp that isn't making good connection with the wire?

Testing the crimp to the spot on the trackpad will ensure you are getting continuity between the trackpad and the PCB.

The fact that your friends keyboard trackpad is working is a really good sign, and shows that it's the KB2040 can totally run this.

Maybe it was a wiring issue after all (I just didn't think to suggest testing the crimps)

MinHyeong-Lee, 2023-06-24:
I tested JST-PH connection with a multi-meter.
Voltage was 3.28V.
And I add a i2c scanning code in firmware from this repo https://github.com/qmk/qmk_firmware/blob/master/keyboards/handwired/onekey/keymaps/i2c_scanner/keymap.c

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

On right side I2C device found at address 0x2A <- I think this means solder joints and wires are right...

Everything seems normal, it's hard to find the cause. haha

chrishoage, 2023-06-24:
oh? This is very good news. This is one of the troubleshooting steps I recommended originally.

If it can find the device then there may be a configuration issue somewhere.

I still think it would be a good idea to try a different KB2040 and set it up to get the touchpad working.

Unfortunately it's still very difficult to debug this remotely, however the fact that the i2c scanner can find the device means that the device is likely working properly

MinHyeong-Lee, 2023-06-25:
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

Chris!! Finally It works.

I don't know why my keyboard's trackpad didn't work.
I still don't know the exact reason.
However, it does not work immediately after copying the uf2 file for firmware change.

If I change the firmware and repeatedly unplug and plug in the usb, and then also unplug and plug the trrs cable, at some point the trackpad becomes stable. It keeps working well after that.

I got scared of changing firmware but now it works fine. I will use it well without changing the firmware..

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

This is my keyboard.

Thank you Chris :)

chrishoage, 2023-06-25:
Wonderful! Glad it's working. I don't know what the issue was either, but perhaps there was a corrupted firmware, or an old firmware with incorrect configuration.

The keyboard looks great - enjoy! Let me know if I can be of any further assistance!

Closed 2023-06-25.

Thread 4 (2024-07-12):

More build info please

pokeygithub, 2024-07-12:
I have ordered the PCBs and they have come in.  Is there a place that documents (with images) the soldering and connections to the touchpad?  I am really excited to move forward but doubt my smarts.

chrishoage, 2024-07-13:
There are build notes here https://github.com/chrishoage/spleeb?tab=readme-ov-file#build-notes which I improved after discussion from https://github.com/chrishoage/spleeb/issues/1

If there is anything unclear please let me know and I can try to improve it further!

memoriasIT, 2024-07-14:
I am currently in the process of building this too. I was a big noob, so I also struggled. I will try to make a PR with a more noob friendly build notes.

I am currently trying to work on the firmware.

pokeygithub, 2024-07-16:
I think what would help greatly are pictures of the completed boards without the case.  Then I can reference how it should look compared to what I have done.   Like the MCU images are great, but it would be awesome to reference the other steps as well.

chrishoage, 2024-07-16:
Sure next time I disassemble my case I'll take some pictures of the completed boards.

Should be in the next few weeks. I've been working on improvements to the trackpad holder (the old one is so terrible!) and adding tenting legs

memoriasIT, 2024-07-17:
@pokeygithub I will try to add them to this issue today!

@chrishoage And those are awesome news! I will wait for that then! 😄
Awesome project as a whole btw, love it!

chrishoage, 2024-07-28:
@pokeygithub I took apart the right half and took these pictures. Is this what you're looking for? If so I can add these to the readme when I publish the 3d model updates for the chassis

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

A bonus picture of the prototype Cirque bracket and tenting legs. Both still need a little more work before they can be shared. Hopefully in a couple more weeks they will be ready!

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

memoriasIT, 2024-07-28:
Looks quite promising! Waiting for the files! ❤️
I will also share all I have here for someone in the future.

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

My Cirque TouchPad came with a ribbon to make it easier to solder so I used it.
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

The tolerances were way too tight and I couldn't solder the cables, so I cut a bit from the right just to make a direct pass.
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

memoriasIT, 2024-07-28:
Looks quite promising! Waiting for the files! ❤️
I will also share all I have here for someone in the future.

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

My Cirque TouchPad came with a ribbon to make it easier to solder so I used it.
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

The tolerances were way too tight and I couldn't solder the cables, so I cut a bit from the right just to make a direct pass.
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

pokeygithub, 2024-07-29:
I really appreciate it everyone.  Now I can get to building with full confidence that I am soldering things on the correct side of the board with correct orientation!

chrishoage, 2024-07-29:
Something that helped me when I was building my boards was to place some masking tape on each to write "Left" and "Right" so I didn't confuse them while adding components

pokeygithub, 2024-08-15:
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

chrishoage, 2024-08-26:
I took away the tenting legs because I was unhappy with them, but the Cirque touchpad was ready for release.

You can read about everything in the pull request which added it

https://github.com/chrishoage/spleeb/pull/5

memoriasIT, 2024-08-27:
Lovely! Can I use the new Cirque enclosure with the old chassis? I assume yes?

chrishoage, 2024-08-27:
No if you print the files as-is they will not work as the footprint of the Cirque enclosure has changed. You may be able to _make_ it fit with some physical modifications to either the top of the chassis or the Cirque enclosure but I've never tried this so YMMV

There were a number of other changes I wanted to make to the chassis so none of the original printed parts will carry over with the new ones.

I go into detail with what has changed in the PR I linked

Closed 2024-07-17.

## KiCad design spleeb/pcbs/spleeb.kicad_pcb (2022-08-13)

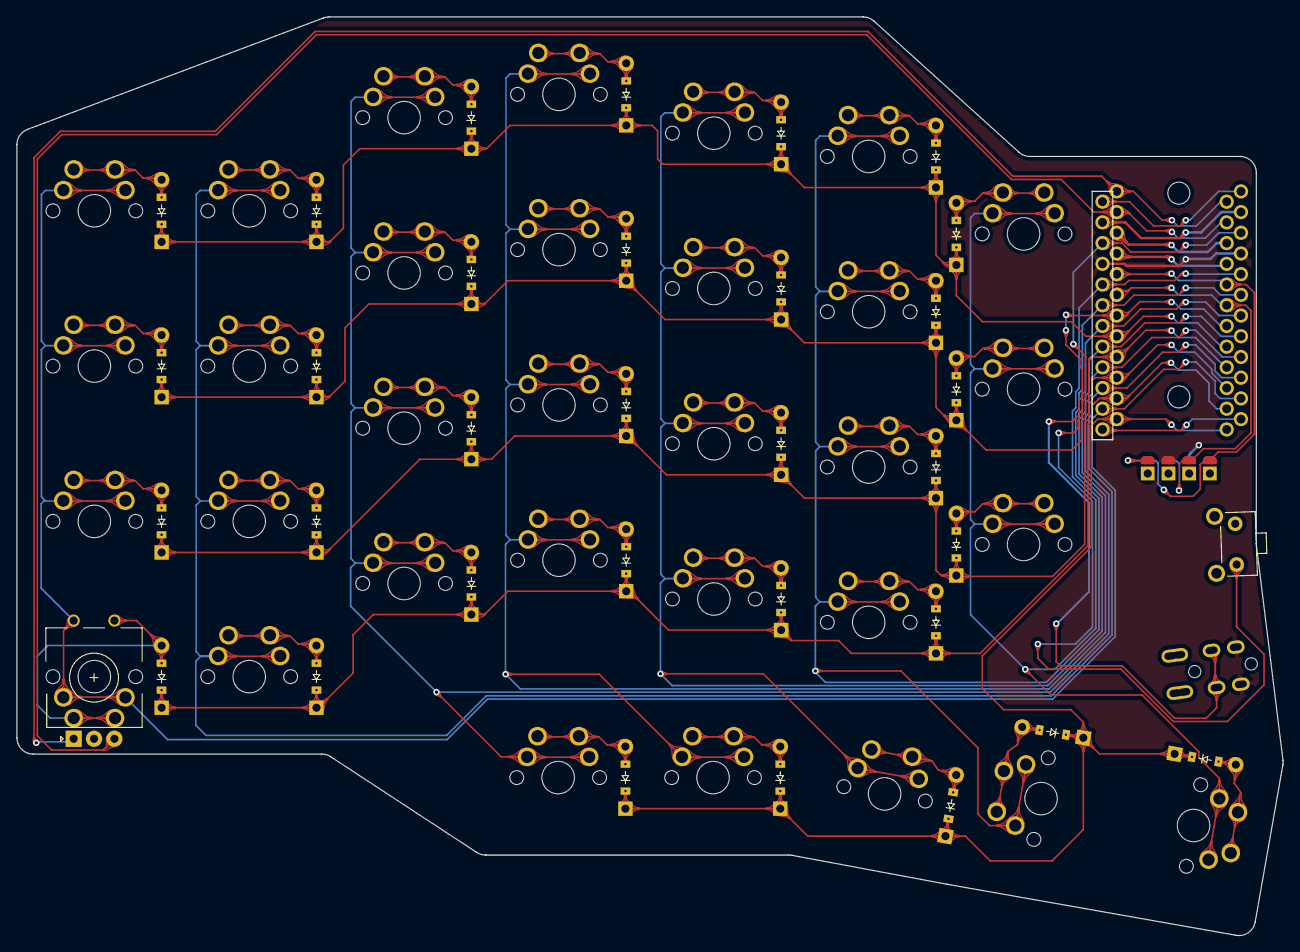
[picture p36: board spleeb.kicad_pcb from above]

Board: 2 copper layers, 155.3 x 112.7 mm, 71 parts (1 on the bottom side), 52 nets.

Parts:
B1: SW_SKHLLCA010
D1, D2, D3, D4, D5, D6, D7, D8, D9, D10, D11, D12, D13, D14, D15, D16, D17, D18, D19, D20, D21, D22, D23, D24, D25, D26, D27, D28, D29, D30, D31, D32: ComboDiode
MCU1: ProMicro
MP1, MP2: Hole
OLED1: OLED-double-sided; OLED-128x32-double-sided
ROT1: rotary_encoder
S1, S2, S3, S4, S5, S6, S7, S8, S9, S10, S11, S12, S13, S14, S15, S16, S17, S18, S19, S20, S21, S22, S23, S24, S25, S26, S27, S28, S29, S30, S31, S32: MX
TRRS1: TRRS-PJ-320A-dual

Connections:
GND: B1.2, MCU1.2, MCU1.15, MCU1.16, OLED1.4, ROT1.C, TRRS1.1, TRRS1.2
P0: MCU1.14, ROT1.B
P1: MCU1.13, ROT1.A
P2: MCU1.17, OLED1.1
P3: MCU1.18, OLED1.2
P4: MCU1.19, TRRS1.3
P5: D4.1, D4.2, D8.1, D8.2, D12.1, D12.2, D16.1, D16.2, D20.1, D20.2, D24.1, D24.2, D27.1, D27.2, MCU1.20
P6: D3.1, D3.2, D7.1, D7.2, D11.1, D11.2, D15.1, D15.2, D19.1, D19.2, D23.1, D23.2, D26.1, D26.2, MCU1.21
P7: D2.1, D2.2, D6.1, D6.2, D10.1, D10.2, D14.1, D14.2, D18.1, D18.2, D22.1, D22.2, D25.1, D25.2, MCU1.22
P8: D1.1, D1.2, D5.1, D5.2, D9.1, D9.2, D13.1, D13.2, D17.1, D17.2, D21.1, D21.2, MCU1.23
P9: D28.1, D28.2, D29.1, D29.2, D30.1, D30.2, D31.1, D31.2, D32.1, D32.2, MCU1.24
P14: MCU1.10, S5.2, S6.2, S7.2, S8.2
P15: MCU1.9, S9.2, S10.2, S11.2, S12.2, S28.2
P16: MCU1.11, ROT1.1, S1.2, S2.2, S3.2, S4.2
P18: MCU1.8, S13.2, S14.2, S15.2, S16.2, S29.2
P19: MCU1.7, S17.2, S18.2, S19.2, S20.2, S30.2
P20: MCU1.6, S21.2, S22.2, S23.2, S24.2, S31.2
P21: MCU1.5, S25.2, S26.2, S27.2, S32.2
RST: B1.1, MCU1.3
VCC: MCU1.4, OLED1.3, TRRS1.4
extra_home: D25.1, D25.2, S25.1
extra_number: D27.1, D27.2, S27.1
extra_top: D26.1, D26.2, S26.1
far_mods: D32.1, D32.2, S32.1
home_mods: D31.1, D31.2, S31.1
index_bottom: D17.1, D17.2, S17.1
index_home: D18.1, D18.2, S18.1
index_number: D20.1, D20.2, S20.1
index_top: D19.1, D19.2, S19.1
inner_bottom: D21.1, D21.2, S21.1
inner_home: D22.1, D22.2, S22.1
inner_number: D24.1, D24.2, S24.1
inner_top: D23.1, D23.2, S23.1
middle_bottom: D13.1, D13.2, S13.1
middle_home: D14.1, D14.2, S14.1
middle_number: D16.1, D16.2, S16.1
middle_top: D15.1, D15.2, S15.1
mod_one_mods: D28.1, D28.2, S28.1
mod_two_mods: D29.1, D29.2, S29.1
near_mods: D30.1, D30.2, S30.1
outer_bottom: D1.1, D1.2, ROT1.2, S1.1
outer_home: D2.1, D2.2, S2.1
outer_number: D4.1, D4.2, S4.1
outer_top: D3.1, D3.2, S3.1
pinky_bottom: D5.1, D5.2, S5.1
pinky_home: D6.1, D6.2, S6.1
pinky_number: D8.1, D8.2, S8.1
pinky_top: D7.1, D7.2, S7.1
ring_bottom: D9.1, D9.2, S9.1
ring_home: D10.1, D10.2, S10.1
ring_number: D12.1, D12.2, S12.1
ring_top: D11.1, D11.2, S11.1

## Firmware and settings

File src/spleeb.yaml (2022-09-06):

# `U` is a predefined unit of measure that means 19.05mm, which is MX spacing
units:
  diode_x: 8.25
  diode_y: 0
  diode_rotate: 90
  mx_cutout: 14
  mx_keycap: 18
  mcu_margin: 30
  outline_fillet: 10
  outline_margin: U/2
  rotary_encoder_x: (U + mcu_margin) / 2
  rotary_encoder_y: -5
  jstph_x: U - 2
  jstph_y: (-U/2) - 2
  trrs_x: (U + (mcu_margin-12.5))
  trrs_y: (U/2)

  # editable
  tangent_angle: -15
  screw_size: 2.2
  screw_size_offset: 0
  tangent_distance: 2
  tab_circle_edge_thickness: 2
  foot_radius: 1
  # editable

  screw_size_radius: (screw_size + screw_size_offset) / 2
  tangent_distance_formula: screw_size_radius + tangent_distance
  tab_circle_formula: screw_size_radius + tab_circle_edge_thickness
  tab_circle_cutout_formula: screw_size_radius

points:
  key:
    tags: [1u]
    footprints:
      switch:
        type: mx
        nets:
          from: =colrow
          to: =column_net
        params:
          reverse: true
      diode:
        type: diode
        anchor:
          shift: [diode_x, diode_y]
          rotate: diode_rotate
        nets:
          from: =colrow
          to: =row_net
        params:
          via_in_pad: true
  zones:
    matrix:
      columns:
        outer:
          key:
            column_net: outer_col
          rows:
            bottom:
              skip: true
        pinky:
          key:
            column_net: pinky_col
        ring:
          key:
            stagger: 0.6U
            column_net: ring_col
        middle:
          key:
            stagger: 0.15U
            column_net: middle_col
        index:
          key:
            stagger: -0.25U
            column_net: index_col
        inner:
          key:
            stagger: -0.15U
            column_net: inner_col
        extra:
          rows:
            bottom:
              skip: true
          key:
            stagger: -0.5u
            column_net: extra_col
            footprints:
              diode:
                anchor:
                  shift: [-diode_x, diode_y]
      rows:
        bottom:
          row_net: bottom_row
          padding: U

        home:
          row_net: home_row
          padding: U
        top:
          row_net: top_row
          padding: U
        number:
          row_net: number_row
          padding: U

    thumb_cluster:
      anchor:
        ref: matrix_inner_bottom
        shift: [-2U, -U]
      rows:
        mods:
          row_net: mods_row
      columns:
        mod_one:
          key:
            column_net: ring_col
        mod_two:
          key:
            column_net: middle_col
        near:
          key:
            spread: U + 2
            stagger: -1
            splay: -10
            column_net: index_col
        home:
          key:
            rotate: 90
            width: 1.25U
            shift: [0, 0.125mx_keycap]
            tags: [125u]
            column_net: inner_col
        far:
          key:
            rotate: -90
            width: 1.25U
            shift: [0, 0.125mx_keycap]
            tags: [125u]
            column_net: extra_col
            footprints:
              diode:
                anchor:
                  shift: [-diode_x, diode_y]
outlines:
  _switches:
    - what: rectangle
      where: true
      size: mx_cutout
      bound: false
  _keycaps_1u:
    - what: rectangle
      size: mx_keycap
      where: /1u/
      bound: false
  _keycaps_125u:
    - what: rectangle
      size: [1.25mx_keycap, mx_keycap]
      where: /125u/
      bound: false
  _plate_tab:
    - operation: stack
      what: polygon
      points:
        - shift: [0, 0]
        - shift: [0, foot_radius]
        - shift: [foot_radius, 0]
          orient: tangent_angle
        - shift: [tangent_distance_formula, 0]
          orient: 90
        - shift: [tab_circle_formula, 0]
          orient: -90
        - shift: [tab_circle_formula, 0]
          orient: -tangent_angle*2
        - shift: [tangent_distance_formula, 0]
          orient: -90
        - shift: [foot_radius, 0]
          orient: 90
        - shift: [foot_radius, 0]
          orient: tangent_angle - 90
      adjust:
        - shift: [0, foot_radius]
        - shift: [-foot_radius, 0]
          orient: tangent_angle
        - shift: [-tangent_distance_formula, 0]
          orient: 90
        - shift: [-tab_circle_formula, 0]
          orient: -90
        - shift: [0, 0]
          orient: -tangent_angle
        - ref: matrix_pinky_bottom
          affect: y
    - operation: subtract
      what: circle
      radius: foot_radius
      where:
        shift: [0, foot_radius]
      adjust:
        - shift: [0, foot_radius]
        - shift: [tab_circle_formula, 0]
          orient: -tangent_angle
        - shift: [tangent_distance_formula, 0]
          orient: -90
        - shift: [-foot_radius, 0]
          orient: -90
        - ref: matrix_pinky_bottom
          affect: y
    - operation: subtract
      what: circle
      radius: foot_radius
      where:
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

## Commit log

2022-08-09 Initial spleebing
    [plate.dxf, preview.dxf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]
2022-08-10 Address DRC errors with GND
    [spleeb-CmtUser.gbr, spleeb-CuBottom.gbl, spleeb-CuTop.gtl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]
2022-08-10 Make preview a dev only outline
    [preview.dxf]
2022-08-11 dont track kicad backups
2022-08-12 Replace jumper pad promicro footprint with reversable thru hole footprint to allow standoffs for oled
    [plate.dxf, spleeb.kicad_pcb]
2022-08-13 Updates for plate including oled cutout
    [pcb_outline.dxf, plate.dxf, plate.kicad_pcb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]
2022-08-14 move from docker to pipx for now and use fixed pcbdraw along with clean
2022-08-14 address issues after 3d model test and build with new build changes
    [pcb_outline.dxf, plate.dxf, plate.kicad_pcb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]
2022-08-27 remove oled mounting posts and replate with jstph. move rot enc, trrs and rst btn
2022-08-27 back to reversable jumper footprint
    [spleeb.yaml]
2022-09-02 add pcb artwork
2022-09-02 fix jstph plate cutout location
    [spleeb.yaml]
2022-09-06 final adjustments to plate
2022-09-06 regenerate files
    [pcb_outline.dxf, plate.dxf, plate.kicad_pcb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]
2022-12-31 add step and fusion files for case
    [Cirque Holder Flat v12.f3d, Spleeb 35mm Cirque Holder Bottom.step, Spleeb 35mm Cirque Holder Top.step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]
2023-04-03 Add sockets to BOM and add MCU Mouting and solder pad instructions
2023-04-25 Add mising reset switch to BOM
2023-05-03 Add visual example of correct MCU and pad solder position
2024-08-26 Add Spleeb Chassis 1.2 Revision models, images, and README updates
    [Angled Cirque Bracket Bezel.step, Angled Cirque Bracket Bracket.step, Angled Cirque Bracket Support.step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]
